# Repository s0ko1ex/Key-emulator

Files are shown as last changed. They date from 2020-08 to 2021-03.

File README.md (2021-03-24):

# Key emulator

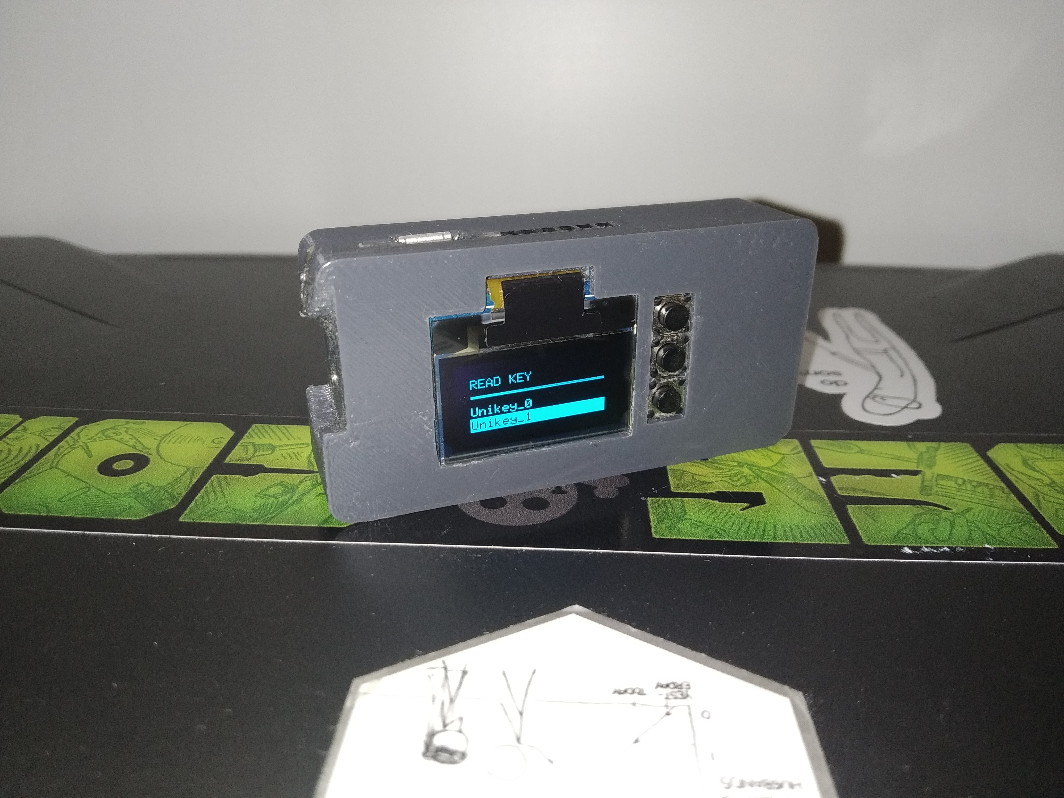
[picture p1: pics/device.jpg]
Device


This project aims at creating a device able to emulate most common key types such as Dallas(iButton), Cyfral and Metacom. A good idea would be to add RFID capabilities, as this type of key is also fairly common.

## Design

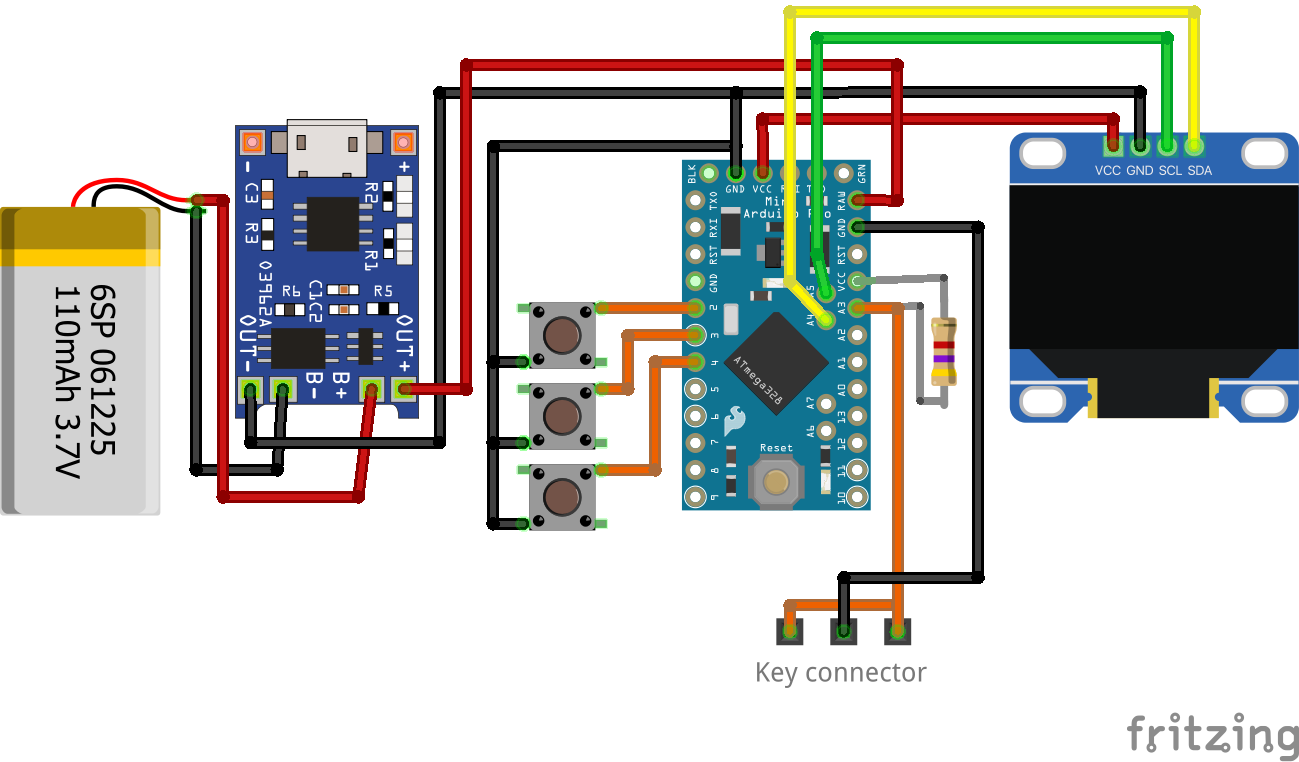
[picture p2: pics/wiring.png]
Wiring


At the heart of the emulator lies a 3.3V Arduino Pro Mini chosen in order to use battery voltage without a boost converter. As the whole project needs to be portable, it has a 150mah battery with TP4056 module for charging and protection. All the information gets displayed on an OLED display and all of this gets controlled by 3 pushbuttons.

Emulator's case gets 3D-printed in 3 parts: main body, part holding arduino and TP4056 module, and the lid. All stl files as well as Fusion 360 master file are available in the repository. More information about printing can be found on [Thingiverse page](https://www.thingiverse.com/thing:4578023).

The wiring is done with simple wires, so considering emulator's small size (66.5 * 16 * 33 mm) it is real messy.

Contact pads for reading/emulating keys are made of simple male headers, which is not accepted by some locks probably due to low contact area and contact pads being dirty, which is elliminated by wired key's shape. So a redesign with a key-style emulation pad is needed.

## Code

Main intention of the [code](https://github.com/s0ko1ex/Key-emulator/blob/master/main.cpp) was its modularity which was achieved to some extend: code for debouncing can be used separatly, screen manager and overall architecture can be adapted to other progects. Nevertheless it was not refactored, which leaves a lot to be desired (comments, multiple files file, etc).

Size of the code is relatively large - 27.1 Kb with available space being 30 Kb, - so a change to a new MCU with more Flash memory must be made, as there will be more key modules. One idea was to substitute Pro Mini for Pro Micro (one USB port for charging and programming, more SRAM, etc), but ditching it altogether and going for an STM32 also seems to be a good idea. Although it will require to adapt code to a whole other architecture, which requires a lot more work.

One of the missing features is low-power mode for using the battery mode efficiently. Moreover, currently there is no indication of battery charge and no safety measures when it is too low.

All of the keys are kept in EEPROM, which can accomodate 25 8-byte keys with 21-character names. So an upgrade to Micro-SD card is needed.

## TODO

- [ ] Do code refactoring, create a couple of libraries
- [ ] Add code dealing with the battery
- [ ] Redesign case
- [ ] Design and manufacture a PCB with a Micro-SD card
- [ ] Change MCU to a more powerful one
- [ ] Add RFID capabilities

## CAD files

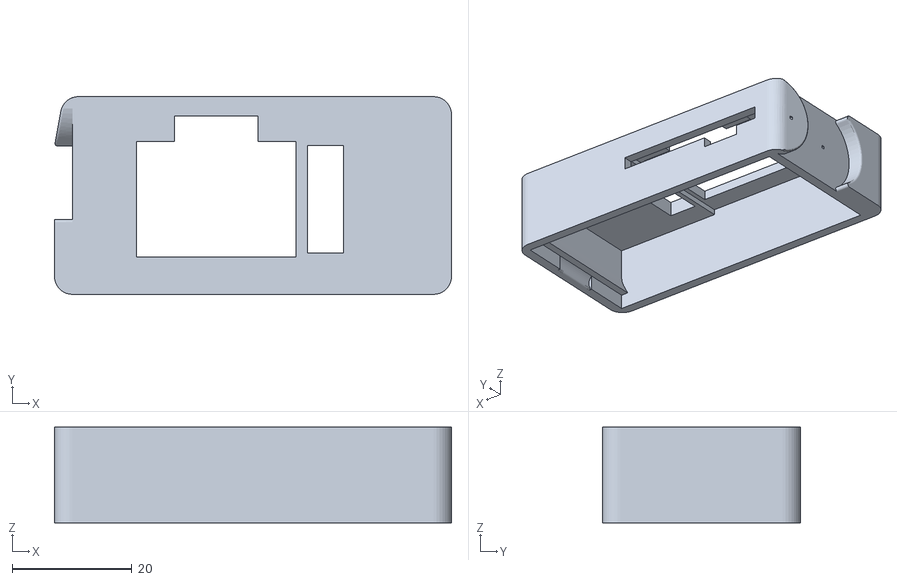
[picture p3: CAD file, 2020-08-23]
printing/main body.stl
66.2 x 33.0 x 16.0

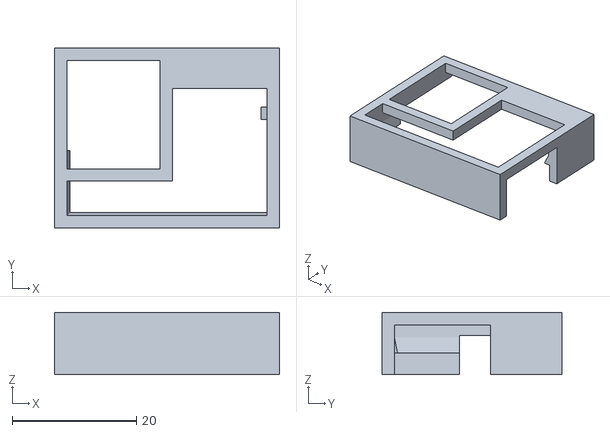
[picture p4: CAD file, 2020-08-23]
printing/parts holder.stl
36.2 x 29.0 x 10.0

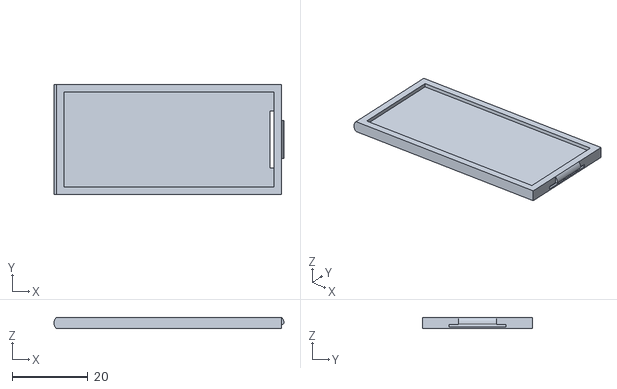
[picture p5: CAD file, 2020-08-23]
printing/lid.stl
60.6 x 29.0 x 3.00

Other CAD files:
printing/key_emulator.f3z

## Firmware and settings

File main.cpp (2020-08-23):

#include <Arduino.h>
#include <Wire.h>
#include <Adafruit_SSD1306.h>
#include <EEPROMex.h>
#include <avr/pgmspace.h>
#include <OneWire.h>
#include <MemoryFree.h>
#include <OneWireHub.h>
#include <DS2401.h>

#define NUM_ROWS 4
#define OFFSET_X 10
#define OFFSET_Y 10
#define FONT_SIZE 1
#define FONT_HEIGHT 8
#define FONT_WIDTH 6
#define LINE_WIDTH 2

#define SCREEN_WIDTH 128
#define SCREEN_HEIGHT 64
#define RESET_PIN 4

#define DEBUG 1

Adafruit_SSD1306 display(SCREEN_WIDTH, SCREEN_HEIGHT, &Wire, RESET_PIN);

/*
 * Some words about keys: I intend to use this device only as an
 * iButton emulator for now, but later might add Metakom and
 * Cyfral keys. iButton key uses 48 bits of information,
 * Metakom - 28, Cyfral - 16, so dword should be plenty for a
 * key. But we also need to keep key type (1 byte) and key name 
 * (let's say 32 characters 1 byte each), so memory diagram looks
 * like this:
 * 
 * Key {
 *      byte type;
 *      char name[32];
 *      byte key[8];
 * }
 * 
 * All of these keys are stored in EEPROM and the first two bytes
 * of it are used for the total number of keys.
 */
#define KEY_PIN A3

#define KEY_NAME_OFFSET 1
#define KEY_NAME_LEN 32
#define KEY_TYPE_OFFSET 0
#define KEY_OFFSET 33
#define KEY_TABLE_OFFSET 2
#define KEY_SIZE 41

struct Key {
    uint64_t cur_key;
    int key_index;
    byte key_type;
};

OneWire ibutton(KEY_PIN);

byte read_key(uint64_t *key);
byte copy_key(uint64_t new_key, Adafruit_SSD1306 *display = NULL);
void emulate_key(uint64_t key);
void save_key(bool original_title = false);
void delete_key(int index);
Key get_key_by_index(int index);
int get_key_offset(int index);
void update_key_by_index(Key key);

void writeByte(byte data, int pin);

byte read_ds1990(uint64_t *key);
byte copy_ds1990(uint64_t new_key, Adafruit_SSD1306 *display = NULL);
void emulate_ds1990(uint64_t key);

const int read_functions[] PROGMEM = {
    (const int)read_ds1990,
};

const int emulate_functions[] PROGMEM = {
    (const int)emulate_ds1990,
};

const int copy_functions[] PROGMEM = {
    (const int)copy_ds1990,
};

void top_button ();
void middle_button ();
void bottom_button ();
void check_buttons ();
bool check_button(int index);
void draw(int offset);

void switch_screen(int offset);
void redraw();

void list_screen_top_button_pressed(int offset);
void list_screen_middle_button_pressed(int offset);
void read_screen_menu_middle_button_pressed(int offset);
void list_screen_bottom_button_pressed(int offset);
void list_screen_draw(int offset);
void key_list_top_button_pressed(int offset);
void key_list_middle_button_pressed(int offset);
void key_menu_middle_button_pressed(int offset); // TODO
void key_list_bottom_button_pressed(int offset);
void key_list_draw(int offset);

void display_screen_top_button_pressed(int offset);
void read_screen_middle_button_pressed(int offset);
void emulate_screen_middle_button_pressed(int offset);
void copy_screen_middle_button_pressed(int offset);
void display_screen_bottom_button_pressed(int offset);
void display_screen_draw(int offset);
void display_key_screen_draw(int offset);

#define SCREEN_TOP_BUTTON_OFFSET 0
#define SCREEN_MIDDLE_BUTTON_OFFSET 1
#define SCREEN_BOTTOM_BUTTON_OFFSET 2
#define SCREEN_DRAW_FUNC_OFFSET 3

#define LIST_SCREEN_N_OFFSET 4
#define LIST_SCREEN_STRINGS_OFFSET 5
#define KEY_LIST_MAIN_OFFSET 4
#define KEY_LIST_N_OFFSET 5
#define KEY_LIST_STRINGS_OFFSET 6

#define DISPLAY_SCREEN_NAME_OFFSET 4
#define DISPLAY_SCREEN_SPECIFIER_OFFSET 5
#define DISPLAY_SCREEN_N_OFFSET 6
#define DISPLAY_SCREEN_OPTIONS_OFFSET 7

#define DISPLAY_SCREEN_NAME_Y_OFFSET 7
/*
 * So... Arduino Pro Mini has 2Kb of SRAM, which is too little for 
 * proper screen managment system, considering 1Kb gets used by 
 * screen buffer. In order to overcome that, screen layout stays 
 * in Flash memory using PROGMEM keyword
 * 
 * Objects can be represented like this:
 * ListScreen {
 *      // offset points to position in array of strings,
 *      // corresponding to the screen, keeping the functions
 *      void (*on_top_button_pressed)(int offset);
 *      void (*on_middle_button_pressed)(int offset);
 *      void (*on_bottom_button_pressed)(int offset);
 *      void (*draw)(int offset);
 * 
 *      int n_childen;
 *      char *names[];
 *      int offsets[];
 * }
 * 
 * KeyList {
 *      // offset points to position in array of strings,
 *      // corresponding to the screen, keeping the functions
 *      void (*on_top_button_pressed)(int offset);
 *      void (*on_middle_button_pressed)(int offset);
 *      void (*on_bottom_button_pressed)(int offset);
 *      void (*draw)(int offset);
 * 
 *      int main_offset;
 *      int n_childen;
 *      char *names[];
 *      int offsets[];
 * }
 * 
 * DisplayScreen {
 *      void (*on_top_button_pressed)(int offset);
 *      void (*on_middle_button_pressed)(int offset);
 *      void (*on_bottom_button_pressed)(int offset);
 *      void (*draw)(int offset);
 * 
 *      char *name;
 *      char *specifier;
 *      int n_options;
 *      char *names[];
 * }
 */

const char str_blank[] PROGMEM = "";
const char str0[] PROGMEM = "READ KEY";
const char str1[] PROGMEM = "EMULATE KEY";
const char str2[] PROGMEM = "COPY KEY";
const char str3[] PROGMEM = "CHOOSE KEY";
const char str4[] PROGMEM = "BRUTE FORCE";
const char str5[] PROGMEM = "BACK";
const char str6[] PROGMEM = "TYPE: ";
const char str7[] PROGMEM = "DS1990";
const char str8[] PROGMEM = "READING...";
const char str9[] PROGMEM = "SUCCESSFULLY READ";
const char str10[] PROGMEM = "SAVE";
const char str11[] PROGMEM = "EMULATE";
const char str12[] PROGMEM = "COPY";
const char str13[] PROGMEM = "CANCEL";
const char str14[] PROGMEM = "EMULATING...";
const char str15[] PROGMEM = "COPYING...";
const char str16[] PROGMEM = "Copying successful";
const char str17[] PROGMEM = "Copying failure";
const char str18[] PROGMEM = "READ BUT NOT IBUTTON";
const char str19[] PROGMEM = "READ BUT WRONG CRC";
const char str20[] PROGMEM = "New key ";
const char str21[] PROGMEM = "DELETE";

const char *const string_arr[] PROGMEM = {str0, str1, str2, str3, str4, str5, str6, str7, str8,
    str9, str10, str11, str12, str13, str14, str15, str16, str17, str18, str19, str20, str21};

#define BUFFER_LEN 64

char buffer[BUFFER_LEN];
bool new_data = false;
void check_serial();
void process_serial();

enum Offset {
    MAIN_MENU = 0,
    READ_SCREEN = 10,
    READ_SUCCESSFUL_MENU = 18,
    KEY_MENU = 31,
    EMULATE_SCREEN = 44,
    COPY_SCREEN = 51,
    NULL_SCREEN
};

const int screens[] PROGMEM = {
    //Main key menu
    (const int)key_list_top_button_pressed,
    (const int)key_list_middle_button_pressed,
    (const int)key_list_bottom_button_pressed,
    (const int)key_list_draw,
    KEY_MENU,
    2,
    (const int)str0,
    (const int)str_blank,
    READ_SCREEN,
    NULL_SCREEN,

    //Read screen
    (const int)display_screen_top_button_pressed,
    (const int)read_screen_middle_button_pressed,
    (const int)display_screen_bottom_button_pressed,
    (const int)display_screen_draw,
    (const int)str0,
    (const int)str6,
    1,
    (const int)str7,

    //Read screen menu
    (const int)list_screen_top_button_pressed,
    (const int)read_screen_menu_middle_button_pressed,
    (const int)list_screen_bottom_button_pressed,
    (const int)list_screen_draw,
    4,
    (const int)str10,
    (const int)str11,
    (const int)str12,
    (const int)str13,
    MAIN_MENU,
    EMULATE_SCREEN,
    COPY_SCREEN,
    MAIN_MENU,

    //Key menu
    (const int)list_screen_top_button_pressed,
    (const int)key_menu_middle_button_pressed,
    (const int)list_screen_bottom_button_pressed,
    (const int)list_screen_draw,
    4,
    (const int)str11,
    (const int)str12,
    (const int)str21,
    (const int)str5,
    EMULATE_SCREEN,
    COPY_SCREEN,
    MAIN_MENU,
    MAIN_MENU,

    //Emulate screen
    (const int)display_screen_top_button_pressed,
    (const int)emulate_screen_middle_button_pressed,
    (const int)display_screen_bottom_button_pressed,
    (const int)display_key_screen_draw,
    (const int)str1,
    (const int)str_blank,
    0,

    //Copy screen
    (const int)display_screen_top_button_pressed,
    (const int)copy_screen_middle_button_pressed,
    (const int)display_screen_bottom_button_pressed,
    (const int)display_key_screen_draw,
    (const int)str2,
    (const int)str_blank,
    0,
};

int prev_screen = 0;
int cur_screen = 0;

int cur_child = 0;

Key global_key = {0, -1, 0};

#define TOP_BUTTON_PIN 2
#define MIDDLE_BUTTON_PIN 3
#define BOTTOM_BUTTON_PIN 4
#define TOP_BUTTON_INDEX 0
#define MIDDLE_BUTTON_INDEX 1
#define BOTTOM_BUTTON_INDEX 2

struct Button {
    byte pin : 4;
    bool executed : 1;
    bool pressed : 1;
    void (*func)(void);
};

struct Button buttons[3] = {
    { TOP_BUTTON_PIN, false, false, top_button },
    { MIDDLE_BUTTON_PIN, false, false, middle_button },
    { BOTTOM_BUTTON_PIN, false, false, bottom_button }
};

void setup() {
    Serial.begin(9600);

    if(!display.begin(SSD1306_SWITCHCAPVCC, 0x3C)) {
        Serial.println(F("SSD1306 allocation failed"));

        for(;;);
    }

    display.setRotation(2);

    pinMode(TOP_BUTTON_PIN, INPUT_PULLUP);
    pinMode(MIDDLE_BUTTON_PIN, INPUT_PULLUP);
    pinMode(BOTTOM_BUTTON_PIN, INPUT_PULLUP);

    switch_screen(MAIN_MENU);
    reinterpret_cast<decltype(draw)*>(pgm_read_word_near(&screens[MAIN_MENU + SCREEN_DRAW_FUNC_OFFSET]))(MAIN_MENU);
}

void loop() {
    check_buttons();
    check_serial();
    process_serial();
}

void check_serial() {
    static boolean recvInProgress = false;
    static byte ndx = 0;
    char startMarker = '[';
    char endMarker = ']';
    char rc;
 
    while (Serial.available() > 0 && !new_data) {
        rc = Serial.read();

        if (recvInProgress == true) {
            if (rc != endMarker) {
                buffer[ndx] = rc;
                ndx++;
                if (ndx >= BUFFER_LEN) {
                    ndx = BUFFER_LEN - 1;
                }
            }
            else {
                buffer[ndx] = '\0'; // terminate the string
                recvInProgress = false;
                ndx = 0;
                new_data = true;
            }
        }

        else if (rc == startMarker) {
            recvInProgress = true;
        }
    }
}

void process_serial() {
    if (new_data) {
        Serial.print("Received: ");
        Serial.println(buffer);

        if (buffer[0] == 'K') {
            int key_num = atoi(buffer + 2);
            EEPROM.updateInt(0, key_num);
        } else if (buffer[0] == 'D') {
            int deleted = atoi(buffer + 2);
            delete_key(deleted);
        } else if (buffer[0] == 'W') {
            byte i = 2, j = 0;
            for (; j < KEY_NAME_LEN && buffer[i] != ' '; i++, j++) {
                buffer[j] = buffer[i];
            }
            if (j < KEY_NAME_LEN)
                buffer[j] = '\0';

            char *cur_pointer = buffer + i + 1;
            global_key.key_type = strtol(cur_pointer, &cur_pointer, 10);

            global_key.cur_key = 0;
            for (j = 0; j < 7; j++) {
                ((uint8_t*)&global_key.cur_key)[j] = (byte)strtol(cur_pointer, &cur_pointer,  16);
            }

            ((uint8_t*)&global_key.cur_key)[7] = ibutton.crc8((uint8_t*)&global_key.cur_key, 7);

            Serial.print(F("Received "));
            for (j = 0; j < 8; j++) {
                if (((uint8_t*)&global_key.cur_key)[j] / 16 == 0)
                    Serial.print(0);
                
                Serial.print(((uint8_t*)&global_key.cur_key)[j], HEX);
                Serial.print(' ');
            }
            Serial.println();

            save_key(true);
        } else if (buffer[0] == 'L') {
            int cur_n_keys = EEPROM.readInt(0);
            Serial.print(F("Number of keys - "));
            Serial.println(cur_n_keys);

            for (int i = 0; i < cur_n_keys; i++) {
                int cur_key_start = get_key_offset(i);

                Serial.print(i);
                Serial.print(' ');

                for (byte j = 0; j < KEY_NAME_LEN && EEPROM.readByte(cur_key_start + KEY_NAME_OFFSET + j) != '\0'; j++) {
                    Serial.print((char)EEPROM.readByte(cur_key_start + KEY_NAME_OFFSET + j));
                }

                Serial.print(' ');
                Serial.print(EEPROM.readByte(cur_key_start + KEY_TYPE_OFFSET));
                Serial.print(' ');

                for (byte j = 0; j < 8; j++) {
                    if (EEPROM.readByte(cur_key_start + KEY_OFFSET + j) / 16 == 0)
                        Serial.print(0);
                    
                    Serial.print(EEPROM.readByte(cur_key_start + KEY_OFFSET + j), HEX);
                    Serial.print(' ');
                }

                Serial.println();
            }
        }

        new_data = false;
    }
}

#pragma region BUTTONS

void check_buttons () {
    for (byte i = 0; i < 3; i++) {
        buttons[i].pressed = !digitalRead(buttons[i].pin);
    }
    
    delay(25);

    for (byte i = 0; i < 3; i++) {
        if (buttons[i].pressed && !digitalRead(buttons[i].pin)) {
            if (!buttons[i].executed) {
                buttons[i].executed = true;
                buttons[i].func();
            }
        } else {
            buttons[i].pressed = false;
            buttons[i].executed = false;
        }
    }
}

bool check_button(int index) {
    buttons[index].pressed = !digitalRead(buttons[index].pin);

    delay(25);

    if (buttons[index].pressed && !digitalRead(buttons[index].pin)) {
        if (!buttons[index].executed) {
            return true;
        }
    } else {
        buttons[index].pressed = false;
        buttons[index].executed = false;
    }

    return false;
}

void top_button () {
    reinterpret_cast<decltype(draw)*>(pgm_read_word_near(&screens[cur_screen + SCREEN_TOP_BUTTON_OFFSET]))(cur_screen);
}

void middle_button () {
    reinterpret_cast<decltype(draw)*>(pgm_read_word_near(&screens[cur_screen + SCREEN_MIDDLE_BUTTON_OFFSET]))(cur_screen);
}

void bottom_button () {
    #if DEBUG
    Serial.println(F("bottom_button"));
    #endif

    reinterpret_cast<decltype(draw)*>(pgm_read_word_near(&screens[cur_screen + SCREEN_BOTTOM_BUTTON_OFFSET]))(cur_screen);
}

#pragma endregion

void switch_screen(int offset) {
    prev_screen = cur_screen;
    cur_screen = offset;
    cur_child = 0;
}

void redraw() {
    reinterpret_cast<decltype(draw)*>(pgm_read_word(&screens[cur_screen + SCREEN_DRAW_FUNC_OFFSET]))(cur_screen);
}

#pragma region LIST_SCREEN

void list_screen_top_button_pressed(int offset) {
    #if DEBUG
    Serial.println(F("list_screen_top_button_pressed"));
    #endif

    byte n_children = (int)pgm_read_word_near(&screens[offset + LIST_SCREEN_N_OFFSET]);
    cur_child = (cur_child + n_children - 1) % n_children;

    redraw();
}

void list_screen_middle_button_pressed(int offset) {
    #if DEBUG
    Serial.println(F("list_screen_middle_button_pressed"));
    #endif

    byte n_children = (int)pgm_read_word_near(&screens[offset + LIST_SCREEN_N_OFFSET]);
    int arr_start = offset + LIST_SCREEN_STRINGS_OFFSET + n_children;
    int new_offset = (int)pgm_read_word_near(&screens[arr_start + cur_child]);

    switch_screen(new_offset);
    redraw();
}

void read_screen_menu_middle_button_pressed(int offset) {
    #if DEBUG
    Serial.println(F("read_screen_menu_middle_button_pressed"));
    #endif
    byte n_children = (int)pgm_read_word_near(&screens[offset + LIST_SCREEN_N_OFFSET]);
    int arr_start = offset + LIST_SCREEN_STRINGS_OFFSET + n_children;
    int new_offset = (int)pgm_read_word_near(&screens[arr_start + cur_child]);

    #if DEBUG
    Serial.print(F("Current child "));
    Serial.println(cur_child);
    #endif

    if (cur_child == 0)
        save_key();
        
    switch_screen(new_offset);
    prev_screen = MAIN_MENU;
    redraw();

    if (new_offset == EMULATE_SCREEN) {
        reinterpret_cast<decltype(draw)*>(pgm_read_word_near(&screens[new_offset + SCREEN_MIDDLE_BUTTON_OFFSET]))(new_offset);
    } else if (new_offset == COPY_SCREEN) {
        reinterpret_cast<decltype(draw)*>(pgm_read_word_near(&screens[new_offset + SCREEN_MIDDLE_BUTTON_OFFSET]))(new_offset);
    }
}

void list_screen_bottom_button_pressed(int offset) {
    #if DEBUG
    Serial.println(F("list_screen_bottom_button_pressed"));
    #endif

    byte n_children = (int)pgm_read_word_near(&screens[offset + LIST_SCREEN_N_OFFSET]);
    cur_child = (cur_child + 1) % n_children;

    redraw();
}

void list_screen_draw(int offset) {
    byte width  = SCREEN_WIDTH - OFFSET_X * 2,
         height = (SCREEN_HEIGHT - OFFSET_Y * 2) / NUM_ROWS,
         text_y_offset = (height - FONT_HEIGHT) / 2 + 1;
    
    byte n_children = (int)pgm_read_word_near(&screens[offset + LIST_SCREEN_N_OFFSET]);
    int arr_start = offset + LIST_SCREEN_STRINGS_OFFSET;

    display.clearDisplay();
    display.setTextSize(FONT_SIZE);

    for (byte start = (cur_child / NUM_ROWS) * NUM_ROWS, i = 0;
            (i < NUM_ROWS) && (start < n_children); i++, start++) {
        strcpy_P(buffer, (char *)pgm_read_word_near(&screens[arr_start + start]));
        display.fillRect(OFFSET_X, OFFSET_Y + height * i, 
                            width, height, start == cur_child);
        display.setCursor(OFFSET_X + 1, OFFSET_Y + height * i + text_y_offset);
        display.setTextColor(start != cur_child);
        display.println(buffer);

        if ((int)pgm_read_word_near(&screens[offset + LIST_SCREEN_STRINGS_OFFSET + n_children + start]) == NULL_SCREEN) {
            display.fillRect(OFFSET_X + 1, OFFSET_Y + height * i + (height - LINE_WIDTH) / 2, display.width() - (OFFSET_X + 1) * 2, LINE_WIDTH, start != cur_child);
        }
    }

    display.display();
}

void key_list_top_button_pressed(int offset) {
    byte n_children = (int)pgm_read_word_near(&screens[offset + KEY_LIST_N_OFFSET]);
    byte n_keys = EEPROM.readInt(0);
    cur_child = (cur_child + n_children + n_keys - 1) % (n_children + n_keys);

    if ((int)pgm_read_word_near(&screens[offset + KEY_LIST_STRINGS_OFFSET + n_children + cur_child]) == NULL_SCREEN)
        cur_child = (cur_child + n_children + n_keys - 1) % (n_children + n_keys);
    
    redraw();
}

void key_list_middle_button_pressed(int offset) {
    byte n_children = (int)pgm_read_word_near(&screens[offset + KEY_LIST_N_OFFSET]);

    if (cur_child < n_children) {
        int arr_start = offset + KEY_LIST_STRINGS_OFFSET + n_children;
        int new_offset = (int)pgm_read_word_near(&screens[arr_start + cur_child]);

        if (new_offset != NULL_SCREEN) {
            switch_screen(new_offset);
            redraw();
        }    
    } else {
        global_key = get_key_by_index(cur_child - n_children);
        
        int new_offset = (int)pgm_read_word(&screens[offset + KEY_LIST_MAIN_OFFSET]);
        switch_screen(new_offset);
        redraw();
    }
}

void key_menu_middle_button_pressed(int offset) {
    byte n_children = (int)pgm_read_word_near(&screens[offset + LIST_SCREEN_N_OFFSET]);
    int arr_start = offset + LIST_SCREEN_STRINGS_OFFSET + n_children;
    int new_offset = (int)pgm_read_word_near(&screens[arr_start + cur_child]);

    if (cur_child == 2) {
        delete_key(global_key.key_index);
    }

    switch_screen(new_offset);
    redraw();
}

void key_list_bottom_button_pressed(int offset) {
    byte n_children = (int)pgm_read_word_near(&screens[offset + KEY_LIST_N_OFFSET]);
    byte n_keys = EEPROM.readInt(0);
    cur_child = (cur_child + 1) % (n_children + n_keys);

    if ((int)pgm_read_word_near(&screens[offset + KEY_LIST_STRINGS_OFFSET + n_children + cur_child]) == NULL_SCREEN)
        cur_child = (cur_child + 1) % (n_children + n_keys);

    redraw();
}

void key_list_draw(int offset) {
    display.clearDisplay();

    byte width  = SCREEN_WIDTH - OFFSET_X * 2,
         height = (SCREEN_HEIGHT - OFFSET_Y * 2) / NUM_ROWS,
         text_y_offset = (height - FONT_HEIGHT) / 2 + 1;
    
    byte n_children = (int)pgm_read_word_near(&screens[offset + KEY_LIST_N_OFFSET]);
    byte n_keys = EEPROM.readInt(0);
    byte start = 0, i = 0;
    
    for (start = (cur_child / NUM_ROWS) * NUM_ROWS, i = 0;
            (i < NUM_ROWS) && (start < n_children); i++, start++) {
        strcpy_P(buffer, (char *)pgm_read_word(&screens[offset + KEY_LIST_STRINGS_OFFSET + start]));

        display.fillRect(OFFSET_X, OFFSET_Y + height * i, 
                            width, height, start == cur_child);
        display.setCursor(OFFSET_X + 1, OFFSET_Y + height * i + text_y_offset);
        display.setTextColor(start != cur_child);
        display.println(buffer);

        if ((int)pgm_read_word_near(&screens[offset + KEY_LIST_STRINGS_OFFSET + n_children + start]) == NULL_SCREEN) {
            display.fillRect(OFFSET_X + 1, OFFSET_Y + height * i + (height - LINE_WIDTH) / 2, display.width() - (OFFSET_X + 1) * 2, LINE_WIDTH, start != cur_child);
        }
    }

    for (byte j = 0; (start < n_keys + n_children) && (i < NUM_ROWS); start++, i++, j++) {
        int key_start = get_key_offset(start - n_children);

        byte k = 0;
        for (;k < KEY_NAME_LEN && EEPROM.readByte(key_start + KEY_NAME_OFFSET + k) != '\0'; k++)
            buffer[k] = EEPROM.readByte(key_start + KEY_NAME_OFFSET + k);
        
        if (k < BUFFER_LEN)
            buffer[k] = '\0';
        
        display.fillRect(OFFSET_X, OFFSET_Y + height * i, 
                            width, height, start == cur_child);
        display.setCursor(OFFSET_X + 1, OFFSET_Y + height * i + text_y_offset);
        display.setTextColor(start != cur_child);
        display.println(buffer);
    }

    display.display();
}

#pragma endregion


#pragma region DISPLAY_SCREEN
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
